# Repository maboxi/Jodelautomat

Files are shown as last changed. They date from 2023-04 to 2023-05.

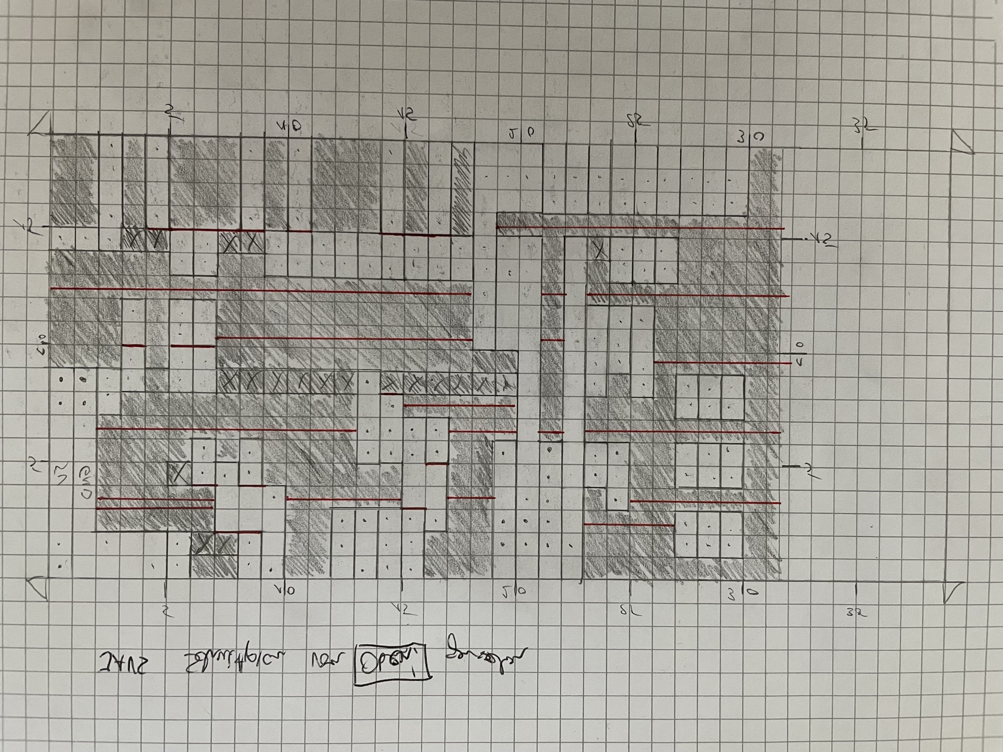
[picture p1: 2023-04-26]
JAVS-Schematics/Breadboard/Copper-Breadboard-CuttingPattern.JPEG

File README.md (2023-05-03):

# Jodelautomat

Der Jodelautomat ist eine Musikbox, welche ohne professionelles Vorwissen entworfen und gebaut wurde.
Das Ziel dieses Repositories ist es, einzelne Aspekte des Jodelautomats neu zu entwerfen, um letztendlich eine verbesserte Version bauen zu können.

## Was kann der Jodelautomat alles?

Derzeit hat der Jodelautomat zwei Funktionen:
 - Musik wiedergeben: der Jodelautomat besitzt einen 3.5mm Klinkeneingang, welcher einen Verstärker (2x50W Main Drivers+ 100W Subwoofer) nutzt, um über zwei in das Gehäuse eingebaute Lautsprecher und einen in den Gehäuseboden integrierten Subwoofer Musik abzuspielen
 - LED-Beleuchtung: der Jodelautomat besitzt 3 LED-Bereiche (unten am Gehäuse, an den zwei Hauptlautsprechern an der Vorderseite und an der Bedienfläche des Jodelautomats), deren Farben entweder manuell ausgewählt oder von einem Mikrocontroller (für "Sound-To-Light") angesteuert werden können; das alte Sound-To-Light-System funtioniert jedoch nur grenzwertig

## Was soll der Jodelautomat alles können?

Ideen für Funktionen (+ Status):
 - Musik-Wiedergabe über Bluetooth
 - (WIP) Funktionierendes Sound-To-Light + LED-Ansteuerung: **JAVS** = Jodelautomat Visual System
 - besseres Gehäuse (leichter, an gewählte Lautsprecher angepasst)
 - neuen Akku + Ladefunktion + Netzadapter

## Repo TODO:
 - Bilder

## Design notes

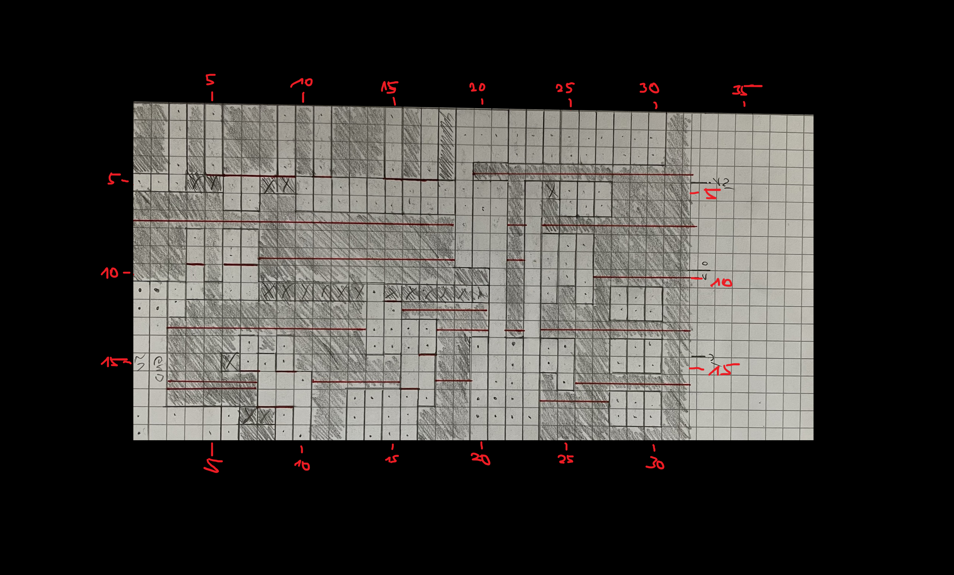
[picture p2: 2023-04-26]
JAVS-Schematics/Breadboard/Copper-Breadboard-CuttingPattern_LineNumbers.png

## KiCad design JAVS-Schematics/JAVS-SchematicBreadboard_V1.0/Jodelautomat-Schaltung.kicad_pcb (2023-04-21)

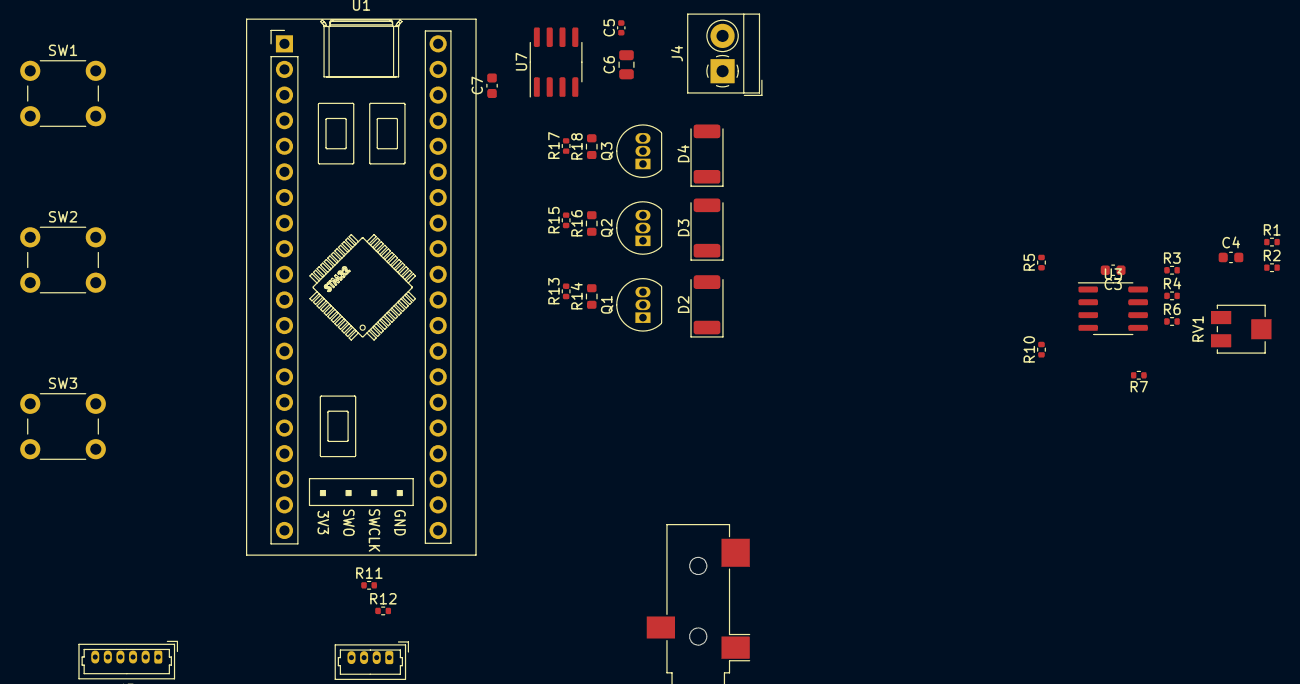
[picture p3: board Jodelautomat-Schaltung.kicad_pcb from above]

Board: 2 copper layers, 38 parts (0 on the bottom side), 33 nets, no tracks yet.

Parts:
C3: 100n; C_0603_1608Metric
C4, C7: 10u; C_0603_1608Metric
C5: 10uF; C_0402_1005Metric
C6: 10uF; C_0805_2012Metric
D2: LED_R; LED_2010_5025Metric
D3: LED_G; LED_2010_5025Metric
D4: LED_B; LED_2010_5025Metric
J1: AudioJack3; Jack_3.5mm_CUI_SJ-3523-SMT_Horizontal
J2: I2C_5V_01x04; Molex_PicoBlade_53047-0410_1x04_P1.25mm_Vertical
J4: Screw_Terminal_01x02; TerminalBlock_4Ucon_1x02_P3.50mm_Horizontal
J5: USART_Full_01x06; Molex_PicoBlade_53047-0610_1x06_P1.25mm_Vertical
Q1, Q2, Q3: BC337; TO-92_Inline
R1, R2: 50k; R_0402_1005Metric
R3, R4, R5, R6, R7, R10: 100k; R_0402_1005Metric
R11, R12, R13, R15, R17: 10k; R_0402_1005Metric
R14: 120R; R_0603_1608Metric
R16, R18: 30R; R_0603_1608Metric
RV1: 100k; Potentiometer_Bourns_3314J_Vertical
SW1: BTN_A; SW_PUSH_6mm
SW2: BTN_B; SW_PUSH_6mm
SW3: BTN_C; SW_PUSH_6mm
U1: BlackPill_F401CCU6_SORTED; BlackPill_F401CCU6
U3: LM358; SOIC-8_3.9x4.9mm_P1.27mm
U7: ICL7660; SOIC-8_3.9x4.9mm_P1.27mm

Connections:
+3.3V: C7.1, D2.2 (A), D3.2 (A), D4.2 (A), J5.4, R10.1, U1.20 (3.3V), U1.21 (VBAT), U1.38 (3.3V)
+5V: C3.2, C4.2, J2.3, J4.1, R11.1, R12.1, U1.18 (5V), U1.40 (5V), U3.4 (V-), U7.8 (V+)
-5V: C3.1, C4.1, C6.2, U3.8 (V+), U7.5 (VOUT)
ADC_IN: R6.2, U1.28 (A2), U3.1
BTN_A: SW1.1, U1.1 (B12)
BTN_B: SW2.1, U1.2 (B13)
BTN_C: SW3.1, U1.3 (B14)
GND: C6.1, C7.2, J1.T, J2.4, J4.2, J5.6, R5.2, R14.1, R16.1, R18.1, SW1.2, SW2.2, SW3.2, U1.19 (G), U1.39 (G), U3.3 (+), U3.5 (+), U7.3 (GND)
LED_1_B: R17.1, U1.35 (B1)
LED_1_G: R15.1, U1.34 (B0)
LED_1_R: R13.1, U1.29 (A3)
unnamed: D2.1 (K), Q1.1 (C)
unnamed: D3.1 (K), Q2.1 (C)
unnamed: D4.1 (K), Q3.1 (C)
unnamed: J1.R, R2.1
unnamed: J1.S, R1.1
unnamed: J2.1, R12.2
unnamed: J2.2, R11.2
unnamed: Q1.2 (B), R13.2
unnamed: Q1.3 (E), R14.2
unnamed: Q2.2 (B), R15.2
unnamed: Q2.3 (E), R16.2
unnamed: Q3.2 (B), R17.2
unnamed: Q3.3 (E), R18.2
unnamed: R1.2, R2.2, RV1.1
unnamed: R3.1, R4.2, U3.7
unnamed: R5.1, R7.1, R10.2
unnamed: R3.2, R6.1, U3.2 (-)
unnamed: R4.1, R7.2, RV1.3, U3.6 (-)
unnamed: C5.1, U7.2 (CAP+)
unnamed: C5.2, U7.4 (CAP-)
USART_RX: J5.3, U1.7 (A10)
USART_TX: J5.2, U1.6 (A9)

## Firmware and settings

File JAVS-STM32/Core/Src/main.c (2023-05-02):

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
/* Includes ------------------------------------------------------------------*/
#include "main.h"
#include "adc.h"
#include "dma.h"
#include "i2c.h"
#include "tim.h"
#include "usart.h"
#include "usb_device.h"
#include "gpio.h"

/* USER CODE BEGIN Includes */

// USB Communication Include
#include "usbd_cdc_if.h"
#include "utils.h"

#include "ffthandler.h"

/* USER CODE END Includes */


/* USER CODE BEGIN PV */

/*
 * USB virtual com port data receiving flags since receive callback cannot be moved out of usbd_cdc_if.c
 */
volatile uint8_t CDCReceiveFlag;
volatile uint32_t CDCReceiveDiscarded;

/*
 * LCD Timeout counter and flag
 */
volatile uint32_t LCD_TimeoutCounter;

/*
 * FFT handler instances
 */
FFTHandler FFT;

/*
 * Double buffer for ADC DMA
 * ADC DMA counters
 */
volatile uint16_t ADC_ReadBuffer[FFT_NUM_SAMPLES * 2];
volatile uint32_t ADC_CallbackCounter;
volatile uint32_t ADC_CallbackResultsSkippedCounter;

/*
 * Button status information
 */
volatile uint8_t ButtonChange_Flag;
volatile uint8_t ButtonStatus_Flag, ButtonStatus;

/* USER CODE END PV */

void SystemClock_Config(void);
/**
 * @brief  The application entry point.
 * @retval int
 */
int main(void)
{
	/* MCU Configuration--------------------------------------------------------*/

	/* Reset of all peripherals, Initializes the Flash interface and the Systick. */
	HAL_Init();

	/* Configure the system clock */
	SystemClock_Config();

	/* Initialize all configured peripherals */
	MX_GPIO_Init();
	MX_DMA_Init();
	MX_ADC1_Init();
	MX_TIM2_Init();
	MX_TIM3_Init();
	MX_TIM4_Init();
	MX_USB_DEVICE_Init();
	MX_I2C1_Init();
	MX_TIM11_Init();
	MX_USART1_UART_Init();
	/* USER CODE BEGIN 2 */

	/*
	 * USB transmission and receiving
	 */
	USB_TxBuffer[USB_TX_BUFFERSIZE - 1] = 0;
	CDCReceiveFlag = 0;
	CDCReceiveDiscarded = 0;

	/*
	 * init I2C LCD
	 */
	LCD2004_I2C lcd;

	LCD_Init(&lcd, LCD_DEFAULT_ADDR);
	LCD_CursorOff(&lcd);

	HAL_Delay(2000);
	LCD_Clear(&lcd);

	/*
	 * Init LED menu and LED strip handling
	 */
	LEDMenu_Init(&lcd);
	LEDStrips_Init();

	/*
	 * Init FFT handler
	 */
	FFTHandler_Init(&FFT);

	/*
	 * ADC DMA init
	 */
	ADC_CallbackCounter = 0;
	uint32_t adcCallbackCounterOld = 0;
	ADC_CallbackResultsSkippedCounter = 0;
	uint32_t adcCallbackResultsSkippedCounterOld = 0;

	HAL_ADC_Start_DMA(&hadc1, (uint32_t*) ADC_ReadBuffer, FFT_NUM_SAMPLES * 2);

	/*
	 * Flags and counters for timed actions via TIM11
	 */
	ButtonChange_Flag = 0;
	ButtonStatus = 0xFF;
	ButtonStatus_Flag = 0;

	LCD_TimeoutCounter = 0; // this will be incremented every 1 ms; check in loop if lcd kathode off or on

	HAL_TIM_Base_Start_IT(&htim11);

	// main loop local variables

	/*
	 * Timing counters for main loop
	 */
	uint32_t timerLast = HAL_GetTick(), timerNow;

	/* USER CODE END 2 */

	/* Infinite loop */
	/* USER CODE BEGIN WHILE */
	while (1)
	{
		/* USER CODE END WHILE */

		/* USER CODE BEGIN 3 */

		/*
		 * Handle USB CDC commands / data
		 */

		if (CDCReceiveFlag)
		{
			if (strncmp((const char*) USB_RxBuffer, "sendfft", 7) == 0)
			{
				FFT.FFTPrintDebugOnceFlag = 1;
			}

			CDCReceiveFlag = 0;
		}

		/*
		 * let handler process new adc readings if available
		 */
		FFTHandler_ProcessData(&FFT, (uint16_t*) ADC_ReadBuffer);

		/*
		 * check if afk -> turn off lcd to reduce power consumption
		 */
		if (LCD_TimeoutCounter >= LCD_TIMEOUT && lcd.lcd_backlight == LCD_BACKLIGHT_ON)
		{
			LCD_BacklightOff(&lcd);
		}

		/*
		 * Handle Button events
		 */
		if (ButtonChange_Flag)
		{
			// if lcd is on, use btn events as menu input
			// else, wake up lcd
			if (lcd.lcd_backlight == LCD_BACKLIGHT_ON)
			{
				if (ButtonStatus_Flag & (1 << BTN_A_FLAG))
				{
					ButtonStatus_Flag &= ~(1 << BTN_A_FLAG);

					// btn back
					LEDMenu_UpdateState(LEDMENU_BTN_BACK, &lcd);
				}

				if (ButtonStatus_Flag & (1 << BTN_B_FLAG))
				{
					ButtonStatus_Flag &= ~(1 << BTN_B_FLAG);

					// btn select
					LEDMenu_UpdateState(LEDMENU_BTN_SELECT, &lcd);
				}

				if (ButtonStatus_Flag & (1 << BTN_C_FLAG))
				{
					ButtonStatus_Flag &= ~(1 << BTN_C_FLAG);

					// btn next item
					LEDMenu_UpdateState(LEDMENU_BTN_NEXTITEM, &lcd);
				}

				if (LEDMenu_StatusFlags & LEDMENU_FLAG_STATECHANGE)
				{
					LEDMenu_StatusFlags &= ~LEDMENU_FLAG_STATECHANGE;
				}
			}
			else
			{
				// backlight is off -> turn it on
				LCD_BacklightOn(&lcd);
				ButtonStatus_Flag = 0;
			}

			LCD_TimeoutCounter = 0;

			ButtonChange_Flag &= ~BTN_EVENT_FLAG;
		}

		/*
		 * debugging output via usb virtual com port
		 */
		timerNow = HAL_GetTick();
		if (timerNow - timerLast >= 1000)
		{
			if ((ADC_CallbackResultsSkippedCounter - adcCallbackResultsSkippedCounterOld) != 0)
			{
				sprintf(USB_TxBuffer, "FFT can't keep up! Skipped %lu ADC reads (%lu total).\r\n", ADC_CallbackResultsSkippedCounter - adcCallbackResultsSkippedCounterOld, ADC_CallbackResultsSkippedCounter);
				USB_PrintDebug(USB_TxBuffer);

				adcCallbackResultsSkippedCounterOld = ADC_CallbackResultsSkippedCounter;
			}

			sprintf(USB_TxBuffer, "1/s: FFT = %lu, ADC = %lu (%u %u), UART = %lu (%lu)\r\n", FFT.fftTransformsCompleted - FFT.fftTransformsCompletedOld, ADC_CallbackCounter - adcCallbackCounterOld, FFT.ADC_ReadMin, FFT.ADC_ReadMax, FFT.uartTxStarted - FFT.uartTxStartedOld, FFT.uartTxMissed - FFT.uartTxMissedOld);
			USB_PrintDebug(USB_TxBuffer);

			adcCallbackCounterOld = ADC_CallbackCounter;
			FFT.fftTransformsCompletedOld = FFT.fftTransformsCompleted;
			FFT.uartTxStartedOld = FFT.uartTxStarted;
			FFT.uartTxMissedOld = FFT.uartTxMissed;

			timerLast = timerNow;
		}

	}
	/* USER CODE END 3 */
}

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
/* USER CODE BEGIN 4 */

// IRQ
/*
 * IRQ for TIM11
 * used for button polling
 */
void IRQ_TIM11()
{
	/*
	 * This IRQ is called every 1ms
	 * Use for counters etc
	 */

	LCD_TimeoutCounter++;

	static uint32_t counterButtons = 0;

	counterButtons++;
	if (counterButtons >= 20)
	{
		uint8_t ButtonRead_A = HAL_GPIO_ReadPin(BTN_A_GPIO_Port, BTN_A_Pin) == GPIO_PIN_SET ? 1 : 0;
		if (ButtonRead_A == 1 && (ButtonStatus & (1 << BTN_A_FLAG)) == 0)
		{
			ButtonStatus |= (1 << BTN_A_FLAG);
		}
		else if (ButtonRead_A == 0 && (ButtonStatus & (1 << BTN_A_FLAG)) != 0)
		{
			ButtonStatus &= ~(1 << BTN_A_FLAG);
			ButtonStatus_Flag |= (1 << BTN_A_FLAG);
			ButtonChange_Flag |= BTN_EVENT_FLAG;
		}

		uint8_t ButtonRead_B = HAL_GPIO_ReadPin(BTN_B_GPIO_Port, BTN_B_Pin) == GPIO_PIN_SET ? 1 : 0;
		if (ButtonRead_B == 1 && (ButtonStatus & (1 << BTN_B_FLAG)) == 0)
		{
			ButtonStatus |= (1 << BTN_B_FLAG);
		}
		else if (ButtonRead_B == 0 && (ButtonStatus & (1 << BTN_B_FLAG)) != 0)
		{
			ButtonStatus &= ~(1 << BTN_B_FLAG);
			ButtonStatus_Flag |= (1 << BTN_B_FLAG);
			ButtonChange_Flag |= BTN_EVENT_FLAG;
		}

		uint8_t ButtonRead_C = HAL_GPIO_ReadPin(BTN_C_GPIO_Port, BTN_C_Pin) == GPIO_PIN_SET ? 1 : 0;
		if (ButtonRead_C == 1 && (ButtonStatus & (1 << BTN_C_FLAG)) == 0)
		{
			ButtonStatus |= (1 << BTN_C_FLAG);
		}
		else if (ButtonRead_C == 0 && (ButtonStatus & (1 << BTN_C_FLAG)) != 0)
		{
			ButtonStatus &= ~(1 << BTN_C_FLAG);
			ButtonStatus_Flag |= (1 << BTN_C_FLAG);
			ButtonChange_Flag |= BTN_EVENT_FLAG;
		}

		counterButtons = 0;
	}
}

// ADC interrupts

void HAL_ADC_ConvCpltCallback(ADC_HandleTypeDef *hadc)
{
	if (hadc == &hadc1)
	{
		ADC_CallbackCounter++;
		if (FFT.FFT_CallbackFlag != FFT_NODATA)
			ADC_CallbackResultsSkippedCounter++;
		FFT.FFT_CallbackFlag = FFT_CALLBACK_FULL;
	}
}

void HAL_ADC_ConvHalfCpltCallback(ADC_HandleTypeDef *hadc)
{
	if (hadc == &hadc1)
	{
		ADC_CallbackCounter++;
		if (FFT.FFT_CallbackFlag != FFT_NODATA)
			ADC_CallbackResultsSkippedCounter++;
		FFT.FFT_CallbackFlag = FFT_CALLBACK_HALF;
	}
}

// IRQ end

// Reset all button flags

void Buttons_ResetFlags()
{
	ButtonChange_Flag = 0;
	ButtonStatus_Flag = 0;
}

/* USER CODE END 4 */
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


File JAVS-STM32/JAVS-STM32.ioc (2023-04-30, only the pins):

Mcu.UserName=STM32F401CEUx
PA0-WKUP.GPIO_Label=BTN_ONBOARD
PA0-WKUP.Signal=GPIO_Input
PA1.Signal=ADCx_IN1
PA10.Signal=USART1_RX
PA11.Signal=USB_OTG_FS_DM
PA12.Signal=USB_OTG_FS_DP
PA13.Signal=SYS_JTMS-SWDIO
PA14.Signal=SYS_JTCK-SWCLK
PA15.GPIO_Label=LED_2_R
PA15.Signal=S_TIM2_CH1_ETR
PA9.Signal=USART1_TX
PB0.GPIO_Label=LED_1_B
PB0.Signal=S_TIM3_CH3
PB1.GPIO_Label=LED_1_G
PB1.Signal=S_TIM3_CH4
PB10.GPIO_Label=LED_1_R
PB10.Signal=S_TIM2_CH3
PB12.GPIO_Label=BTN_C
PB12.Signal=GPIO_Input
PB13.GPIO_Label=BTN_B
PB13.Signal=GPIO_Input
PB14.GPIO_Label=BTN_A
PB14.Signal=GPIO_Input
PB3.GPIO_Label=LED_2_G
PB3.Signal=S_TIM2_CH2
PB4.GPIO_Label=LED_2_B
PB4.Signal=S_TIM3_CH1
PB5.GPIO_Label=LED_3_R
PB5.Signal=S_TIM3_CH2
PB6.GPIO_Label=LED_3_G
PB6.Signal=S_TIM4_CH1
PB7.GPIO_Label=LED_3_B
PB7.Signal=S_TIM4_CH2
PB8.Signal=I2C1_SCL
PB9.Signal=I2C1_SDA
PC13-ANTI_TAMP.GPIO_Label=LED_ONBOARD
PC13-ANTI_TAMP.Signal=GPIO_Output

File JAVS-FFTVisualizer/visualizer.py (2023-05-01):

import matplotlib.pyplot as plt
import matplotlib.animation as animation
import serial#
import io
from math import sin, atan2

import struct

#SERIALCOM_USED = 'CDC' # not supported right now!
SERIALCOM_USED = 'UART'

SERIALPORT_CDC = 'COM7'
SERIALPORT_UART = 'COM8'

CDC_FFTSTART = b'-- FFT Data START --'
CDC_FFTEND = b'-- FFT Data END --'

BAUDRATE = 2000000
UART_FLAG = b'\x00\x00\x00\x00\x00\x00\x00\x00'
UART_NUMSAMPLES = 512
UART_NUMSAMPLES_HALF = int(UART_NUMSAMPLES / 2)

FFT_NUMSAMPLES = 4096
FFT_NUMCYCLES = 33


serialHandle: serial.Serial = None
axTop = None
axBot = None
fftMaxFrequency = FFT_NUMSAMPLES * FFT_NUMCYCLES / 2 # 35 sampling cycles per second, 4096 samples / cycle

FFT_NUMRECURSIVEMAX = 60
fftRecursiveMaxValues = [0] * 60
fftRecursiveMaxCounter = 0



def serialWaitFor(s, name):
    global serialHandle
    
    while(True):
        line = serialHandle.readline()
        if(s in line):
            print(f"Received correct {name}: {line}")
            break
        else:
            print(f"Received: '{line}'")
            pass
    
def animatePlotCDC(i):
    pass

def animatePlotUART(i):
    global serialHandle
    global axTop
    global axBot
    global fftMaxFrequency
    global fftRecursiveMaxValues
    global fftRecursiveMaxCounter
    
    print("\nWaiting for UART data... ")
    
    receivedData = None
    
    while(True):
        receivedData = serialHandle.read_until(UART_FLAG)
        if(len(receivedData) == (UART_NUMSAMPLES * 4 + len(UART_FLAG))):
            break
        else:
            print(f"Discarded serial read with {len(receivedData)} bytes...")
    
    # remove UART flag from data
    receivedData = receivedData[:(len(receivedData) - len(UART_FLAG))]

    # convert byte array into float array
    dataArray = struct.unpack(f"{UART_NUMSAMPLES}f", receivedData)
    
    print(f"Received {len(receivedData)} bytes and converted them into {len(dataArray)} numbers")
    
    fftFrequencyPerBin = fftMaxFrequency / (FFT_NUMSAMPLES / 2)

    
    # calculate fft results from complex result data
    realFFT = [dataArray[2*i] for i in range(0, UART_NUMSAMPLES_HALF)]
    imaginaryFFT = [dataArray[2*i + 1] for i in range(0, UART_NUMSAMPLES_HALF)]
    angleFFT = [atan2(imaginaryFFT[i], realFFT[i]) for i in range(0, UART_NUMSAMPLES_HALF)]
    powerFFT = [realFFT[i] * realFFT[i] + imaginaryFFT[i] * imaginaryFFT[i] for i in range(0, UART_NUMSAMPLES_HALF)]
    
    powerMax = max(powerFFT)

    fftRecursiveMaxValues[fftRecursiveMaxCounter] = powerMax * 1.1
    fftRecursiveMaxValuesSloped = fftRecursiveMaxValues
    
    slope = 1 / (16 * FFT_NUMRECURSIVEMAX)
    
    for i in range(0, FFT_NUMRECURSIVEMAX):
        j =  (i + fftRecursiveMaxCounter) % FFT_NUMRECURSIVEMAX
        fftRecursiveMaxValuesSloped[j] = fftRecursiveMaxValuesSloped[j] * (1 - i * slope)
        
        
    fftRecursiveMaxCounter = (fftRecursiveMaxCounter + 1) % FFT_NUMRECURSIVEMAX
    
    fftRecursiveMax = max(fftRecursiveMaxValuesSloped)
    
    print(fftRecursiveMax)

    plotXValues = [fftFrequencyPerBin * x for x in range(0, UART_NUMSAMPLES_HALF)]
    

    
    axTop.clear()
    axTop.set_xlim(0, fftFrequencyPerBin * (UART_NUMSAMPLES_HALF + 1))
    axTop.plot(plotXValues, powerFFT)
    axTop.set_ylim(0, fftRecursiveMax)
    
    '''
    (phaMin, phaMax) = axPhase.get_ylim()
    phaMin = min(phaMin, min(angleFFT))
    phaMax = max(phaMax, max(angleFFT))
    
    axPhase.clear()
    axPhase.set_xlim(0, fftFrequencyPerBin * (UART_NUMSAMPLES_HALF + 1))
    axPhase.plot(plotXValues, angleFFT)
    axPhase.set_ylim(phaMin, phaMax)
    '''
    
    (_, powMax) = axBot.get_ylim()
    powMax = max(powMax, powerMax)
    
    axBot.clear()
    axBot.set_xlim(0, fftFrequencyPerBin * (UART_NUMSAMPLES_HALF + 1))
    axBot.plot(plotXValues, powerFFT)
    axBot.set_ylim(0, powMax)


if __name__ == '__main__':
    if(SERIALCOM_USED == 'UART'):
        serialHandle  = serial.Serial(port=SERIALPORT_UART, baudrate = BAUDRATE)
    elif(SERIALCOM_USED == 'CDC'):
        serialHandle  = serial.Serial(port=SERIALPORT_CDC)
    else:
        print(f"Unknown serial port selection (var SERIALCOM_USED = {SERIALCOM_USED})!")
        exit(1)
    
    serialHandle.set_buffer_size(65535, 128)
    
    print("Serial connection established!")
    
    fig1 = plt.figure(1)
    
    axTop = fig1.add_subplot(2, 1, 1)
    axBot = fig1.add_subplot(2, 1, 2)
    
    axTop.plot([], [])
    axBot.plot([], [])
    
    
    if(SERIALCOM_USED == 'UART'):
        fftFrequencyPerBin = fftMaxFrequency / FFT_NUMSAMPLES
        
        axTop.set_xlim(0, fftFrequencyPerBin * UART_NUMSAMPLES)
        axBot.set_xlim(0, fftFrequencyPerBin * UART_NUMSAMPLES)
        
        axTop.set_ylim(-1.0, 1.0)
        axBot.set_ylim(-1.0, 1.0)
        
        ani = animation.FuncAnimation(fig1, animatePlotUART, interval=1) # max 50 fps
    elif(SERIALCOM_USED == 'CDC'):
        ani = animation.FuncAnimation(fig1, animatePlotCDC, interval=3000)
    
    plt.show()

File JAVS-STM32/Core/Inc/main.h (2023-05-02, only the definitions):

#define LED_ONBOARD_Pin GPIO_PIN_13
#define LED_ONBOARD_GPIO_Port GPIOC
#define BTN_ONBOARD_Pin GPIO_PIN_0
#define BTN_ONBOARD_GPIO_Port GPIOA
#define LED_1_B_Pin GPIO_PIN_0
#define LED_1_B_GPIO_Port GPIOB
#define LED_1_G_Pin GPIO_PIN_1
#define LED_1_G_GPIO_Port GPIOB
#define LED_1_R_Pin GPIO_PIN_10
#define LED_1_R_GPIO_Port GPIOB
#define BTN_C_Pin GPIO_PIN_12
#define BTN_C_GPIO_Port GPIOB
#define BTN_B_Pin GPIO_PIN_13
#define BTN_B_GPIO_Port GPIOB
#define BTN_A_Pin GPIO_PIN_14
#define BTN_A_GPIO_Port GPIOB
#define LED_2_R_Pin GPIO_PIN_15
#define LED_2_R_GPIO_Port GPIOA
#define LED_2_G_Pin GPIO_PIN_3
#define LED_2_G_GPIO_Port GPIOB
#define LED_2_B_Pin GPIO_PIN_4
#define LED_2_B_GPIO_Port GPIOB
#define LED_3_R_Pin GPIO_PIN_5
#define LED_3_R_GPIO_Port GPIOB
#define LED_3_G_Pin GPIO_PIN_6
#define LED_3_G_GPIO_Port GPIOB
#define LED_3_B_Pin GPIO_PIN_7
#define LED_3_B_GPIO_Port GPIOB
#define LCD_TIMEOUT 20000
#define FFT_NUM_SAMPLES 4096
#define FFT_UARTBUFFERSIZE 512
#define FFT_UARTBUFFERFLAGBYTES 8
#define FFT_NODATA 		(1<<0)
#define FFT_CALLBACK_HALF 	(1<<1)
#define FFT_CALLBACK_FULL 	(1<<2)
#define BTN_EVENT_FLAG 1
#define BTN_A_FLAG 0
#define BTN_B_FLAG 1
#define BTN_C_FLAG 2

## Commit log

2023-04-20 adding existing project to repository
    [fftvisualization.xlsx]
2023-04-20 moved invalid output data to new folder; invalid bc signal connected to wrong pin
2023-04-20 copied schematic files into git repo
    [Jodelautomat-Schaltung.kicad_pcb, Jodelautomat-Schaltung.kicad_sch]
2023-04-20 added uart fft output
    [Jodelautomat-Schaltung.kicad_pcb, Jodelautomat-Schaltung.kicad_sch, fftvisualization.xlsx]
2023-04-21 moving pins around to have a better breadboard layout
    [Jodelautomat-Schaltung.kicad_sch]
2023-04-21 copied KiCAD project for breadboard layout; removed big 3d files
    [Jodelautomat-Schaltung.kicad_pcb, Jodelautomat-Schaltung.kicad_sch]
2023-04-22 some modifications for breadboard creation; removed onboard leds for all stips except strip 1
    [Jodelautomat-Schaltung.kicad_sch]
2023-04-24 breadboard version was created and tested; resistor values for 3.3V/2 rail changed to 4.7k; added LTSpice simulations
    [fftvisualization.xlsx]
2023-04-26 changed pwm frequency from 100Hz to 1kHz
2023-04-28 created simple matplotlib visualizer that reads mc uart output; found problem with fft (only ~1 out of 3 ffts is correct, rest has alot of noise)
    [JAVS-STM32.ioc, main.c, main.h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]
2023-04-30 reworked adc reading conversion and fft calculation; live visualizer using matplotlib now working and plotting fft power + phase
    [analogreadingscheck.xlsx]
2023-05-02 renamed schematics folder since it not only contains KiCAD files but also breadboard layout information
    [Jodelautomat-Schaltung.kicad_pcb, Jodelautomat-Schaltung.kicad_sch]
2023-05-02 removed breadboard KiCAD project since my attempt to use it for breadboard creation wasn't too useful
    [Jodelautomat-Schaltung.kicad_pcb, Jodelautomat-Schaltung.kicad_sch]

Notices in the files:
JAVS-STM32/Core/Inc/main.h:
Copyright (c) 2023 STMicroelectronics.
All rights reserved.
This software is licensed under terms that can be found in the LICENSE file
